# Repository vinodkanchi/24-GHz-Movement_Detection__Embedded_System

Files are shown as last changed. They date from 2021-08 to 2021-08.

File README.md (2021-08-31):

# 24-GHz-Movement_Detection__Embedded_System
The project is movement detection system where we design a PCB board for a Bandpass filter for allowing specific frequency using KiCad, then we do an embedded detection system using FreeSo-2, here we use ADC,DAC and LED's. Finally the next step is to test the model for the required frequency and gain measurements.

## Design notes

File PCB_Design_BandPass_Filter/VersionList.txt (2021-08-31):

22.05.2021, Vinod Kumar Kanchi
------------------------

Note: Every Version gets an entry, explaining their stpeciality. e.g.:

15.03.2021 - Astabel Multivibrarot, Vesion 1.0
------------------------------------------------
Feature: Single Supply Version, Four layer PCB

Radar_1v1.0

 Inital layout

Radar_1v1.1
 Changed a few resources after review by Prof. Hubrich. 
 Changed With long track from Radar sensor to capacitor,Resistor, capacitor and to Amplifier ---- Now having comparitable short track from Radar sensor to capacitor,resistor and amplifier.
 Track on 5V power plane --- Made 5V power plane on layer 2. Elimanted track from P1 to P4 pin 6 and 7.
 Rearranged few components.

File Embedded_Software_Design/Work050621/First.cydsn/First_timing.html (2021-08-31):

# Static Timing Analysis

Project : | First
Build Time : | 06/06/21 22:14:28
Device : | CY8C5888AXI-LP096
Temperature : | -40C - 85/125C
VDDA : | 5.00
VDDABUF : | 5.00
VDDD : | 5.00
VDDIO0 : | 5.00
VDDIO1 : | 5.00
VDDIO2 : | 5.00
VDDIO3 : | 5.00
VUSB : | 5.00
Voltage : | 5.0

Expand All | Collapse All | Show All Paths | Hide All Paths

+ Timing Violation Section

No Timing Violations

+ Clock Summary Section

Clock | Domain | Nominal Frequency | Required Frequency | Maximum Frequency | Violation
ADC_DelSig_Ext_CP_Clk | ADC_DelSig_Ext_CP_Clk | 24.000 MHz | 24.000 MHz | N/A
ADC_DelSig_Ext_CP_Clk(routed) | ADC_DelSig_Ext_CP_Clk(routed) | 24.000 MHz | 24.000 MHz | N/A
ClockBlock/aclk_glb_ff_0 | ClockBlock/aclk_glb_ff_0 | UNKNOWN | UNKNOWN | N/A
CyILO | CyILO | 1.000 kHz | 1.000 kHz | N/A
CyIMO | CyIMO | 3.000 MHz | 3.000 MHz | N/A
CyMASTER_CLK | CyMASTER_CLK | 24.000 MHz | 24.000 MHz | N/A
CyBUS_CLK | CyMASTER_CLK | 24.000 MHz | 24.000 MHz | 62.649 MHz
ADC_DelSig_theACLK | CyMASTER_CLK | 127.660 kHz | 127.660 kHz | N/A
UART_IntClock | CyMASTER_CLK | 76.677 kHz | 76.677 kHz | 49.694 MHz
WaveDAC8_DacClk | CyMASTER_CLK | 10.000 kHz | 10.000 kHz | N/A
CyPLL_OUT | CyPLL_OUT | 24.000 MHz | 24.000 MHz | N/A
WaveDAC8_DacClk(routed) | WaveDAC8_DacClk(routed) | 10.000 kHz | 10.000 kHz | N/A
\ADC_DelSig:DSM\/dec_clock | \ADC_DelSig:DSM\/dec_clock | UNKNOWN | UNKNOWN | N/A

+ Register to Register Section

+ Setup Subsection

+ Source Clock : CyBUS_CLK : Positive edge(Required Frequency 24 MHz)

+ Destination Clock : UART_IntClock : Positive edge(Required Frequency 76.6773 kHz)

Path Delay Requirement : 41.6667ns(24 MHz)

Affects clock : CyMASTER_CLK

Source | Destination | FMax | Delay (ns) | Slack (ns) | Violation
Rx_1(0)/fb | \UART:BUART:sRX:RxShifter:u0\/route_si | 62.649 MHz | 15.962 | 25.705

Type | Location | Fanout | Instance/Net | Source | Dest | Delay (ns)
iocell4 | P2[0] | 1 | Rx_1(0) | Rx_1(0)/in_clock | Rx_1(0)/fb | 2.187
Route | | 1 | Net_21 | Rx_1(0)/fb | \UART:BUART:rx_postpoll\/main_1 | 4.664
macrocell6 | U(0,4) | 1 | \UART:BUART:rx_postpoll\ | \UART:BUART:rx_postpoll\/main_1 | \UART:BUART:rx_postpoll\/q | 3.350
Route | | 1 | \UART:BUART:rx_postpoll\ | \UART:BUART:rx_postpoll\/q | \UART:BUART:sRX:RxShifter:u0\/route_si | 2.291
datapathcell3 | U(0,4) | 1 | \UART:BUART:sRX:RxShifter:u0\ | | SETUP | 3.470
Clock | | | | | Skew | 0.000
Rx_1(0)/fb | \UART:BUART:rx_last\/main_0 | 87.268 MHz | 11.459 | 30.208

Type | Location | Fanout | Instance/Net | Source | Dest | Delay (ns)
iocell4 | P2[0] | 1 | Rx_1(0) | Rx_1(0)/in_clock | Rx_1(0)/fb | 2.187
Route | | 1 | Net_21 | Rx_1(0)/fb | \UART:BUART:rx_last\/main_0 | 5.762
macrocell25 | U(0,3) | 1 | \UART:BUART:rx_last\ | | SETUP | 3.510
Clock | | | | | Skew | 0.000
Rx_1(0)/fb | \UART:BUART:rx_state_2\/main_8 | 87.352 MHz | 11.448 | 30.219

Type | Location | Fanout | Instance/Net | Source | Dest | Delay (ns)
iocell4 | P2[0] | 1 | Rx_1(0) | Rx_1(0)/in_clock | Rx_1(0)/fb | 2.187
Route | | 1 | Net_21 | Rx_1(0)/fb | \UART:BUART:rx_state_2\/main_8 | 5.751
macrocell19 | U(0,3) | 1 | \UART:BUART:rx_state_2\ | | SETUP | 3.510
Clock | | | | | Skew | 0.000
Rx_1(0)/fb | \UART:BUART:pollcount_1\/main_3 | 88.747 MHz | 11.268 | 30.399

Type | Location | Fanout | Instance/Net | Source | Dest | Delay (ns)
iocell4 | P2[0] | 1 | Rx_1(0) | Rx_1(0)/in_clock | Rx_1(0)/fb | 2.187
Route | | 1 | Net_21 | Rx_1(0)/fb | \UART:BUART:pollcount_1\/main_3 | 5.571
macrocell22 | U(0,5) | 1 | \UART:BUART:pollcount_1\ | | SETUP | 3.510
Clock | | | | | Skew | 0.000
Rx_1(0)/fb | \UART:BUART:pollcount_0\/main_2 | 88.747 MHz | 11.268 | 30.399

Type | Location | Fanout | Instance/Net | Source | Dest | Delay (ns)
iocell4 | P2[0] | 1 | Rx_1(0) | Rx_1(0)/in_clock | Rx_1(0)/fb | 2.187
Route | | 1 | Net_21 | Rx_1(0)/fb | \UART:BUART:pollcount_0\/main_2 | 5.571
macrocell23 | U(0,5) | 1 | \UART:BUART:pollcount_0\ | | SETUP | 3.510
Clock | | | | | Skew | 0.000
Rx_1(0)/fb | \UART:BUART:rx_state_0\/main_9 | 96.516 MHz | 10.361 | 31.306

Type | Location | Fanout | Instance/Net | Source | Dest | Delay (ns)
iocell4 | P2[0] | 1 | Rx_1(0) | Rx_1(0)/in_clock | Rx_1(0)/fb | 2.187
Route | | 1 | Net_21 | Rx_1(0)/fb | \UART:BUART:rx_state_0\/main_9 | 4.664
macrocell16 | U(0,4) | 1 | \UART:BUART:rx_state_0\ | | SETUP | 3.510
Clock | | | | | Skew | 0.000
Rx_1(0)/fb | \UART:BUART:rx_status_3\/main_6 | 96.516 MHz | 10.361 | 31.306

Type | Location | Fanout | Instance/Net | Source | Dest | Delay (ns)
iocell4 | P2[0] | 1 | Rx_1(0) | Rx_1(0)/in_clock | Rx_1(0)/fb | 2.187
Route | | 1 | Net_21 | Rx_1(0)/fb | \UART:BUART:rx_status_3\/main_6 | 4.664
macrocell24 | U(0,4) | 1 | \UART:BUART:rx_status_3\ | | SETUP | 3.510
Clock | | | | | Skew | 0.000

+ Source Clock : UART_IntClock : Positive edge(Required Frequency 76.6773 kHz)

+ Destination Clock : UART_IntClock : Positive edge(Required Frequency 76.6773 kHz)

Path Delay Requirement : 13041.7ns(76.6773 kHz)

Source | Destination | FMax | Delay (ns) | Slack (ns) | Violation
\UART:BUART:tx_state_2\/q | \UART:BUART:sTX:sCLOCK:TxBitClkGen\/cs_addr_0 | 49.694 MHz | 20.123 | 13021.544

Type | Location | Fanout | Instance/Net | Source | Dest | Delay (ns)
macrocell13 | U(1,3) | 1 | \UART:BUART:tx_state_2\ | \UART:BUART:tx_state_2\/clock_0 | \UART:BUART:tx_state_2\/q | 1.250
Route | | 1 | \UART:BUART:tx_state_2\ | \UART:BUART:tx_state_2\/q | \UART:BUART:counter_load_not\/main_3 | 5.686
macrocell2 | U(1,5) | 1 | \UART:BUART:counter_load_not\ | \UART:BUART:counter_load_not\/main_3 | \UART:BUART:counter_load_not\/q | 3.350
Route | | 1 | \UART:BUART:counter_load_not\ | \UART:BUART:counter_load_not\/q | \UART:BUART:sTX:sCLOCK:TxBitClkGen\/cs_addr_0 | 3.647
datapathcell2 | U(1,3) | 1 | \UART:BUART:sTX:sCLOCK:TxBitClkGen\ | | SETUP | 6.190
Clock | | | | | Skew | 0.000
\UART:BUART:tx_state_1\/q | \UART:BUART:sTX:sCLOCK:TxBitClkGen\/cs_addr_0 | 49.803 MHz | 20.079 | 13021.588

Type | Location | Fanout | Instance/Net | Source | Dest | Delay (ns)
macrocell11 | U(1,4) | 1 | \UART:BUART:tx_state_1\ | \UART:BUART:tx_state_1\/clock_0 | \UART:BUART:tx_state_1\/q | 1.250
Route | | 1 | \UART:BUART:tx_state_1\ | \UART:BUART:tx_state_1\/q | \UART:BUART:counter_load_not\/main_0 | 5.642
macrocell2 | U(1,5) | 1 | \UART:BUART:counter_load_not\ | \UART:BUART:counter_load_not\/main_0 | \UART:BUART:counter_load_not\/q | 3.350
Route | | 1 | \UART:BUART:counter_load_not\ | \UART:BUART:counter_load_not\/q | \UART:BUART:sTX:sCLOCK:TxBitClkGen\/cs_addr_0 | 3.647
datapathcell2 | U(1,3) | 1 | \UART:BUART:sTX:sCLOCK:TxBitClkGen\ | | SETUP | 6.190
Clock | | | | | Skew | 0.000
\UART:BUART:tx_state_0\/q | \UART:BUART:sTX:sCLOCK:TxBitClkGen\/cs_addr_0 | 50.355 MHz | 19.859 | 13021.808

Type | Location | Fanout | Instance/Net | Source | Dest | Delay (ns)
macrocell12 | U(0,4) | 1 | \UART:BUART:tx_state_0\ | \UART:BUART:tx_state_0\/clock_0 | \UART:BUART:tx_state_0\/q | 1.250
Route | | 1 | \UART:BUART:tx_state_0\ | \UART:BUART:tx_state_0\/q | \UART:BUART:counter_load_not\/main_1 | 5.422
macrocell2 | U(1,5) | 1 | \UART:BUART:counter_load_not\ | \UART:BUART:counter_load_not\/main_1 | \UART:BUART:counter_load_not\/q | 3.350
Route | | 1 | \UART:BUART:counter_load_not\ | \UART:BUART:counter_load_not\/q | \UART:BUART:sTX:sCLOCK:TxBitClkGen\/cs_addr_0 | 3.647
datapathcell2 | U(1,3) | 1 | \UART:BUART:sTX:sCLOCK:TxBitClkGen\ | | SETUP | 6.190
Clock | | | | | Skew | 0.000
\UART:BUART:sTX:sCLOCK:TxBitClkGen\/ce0_reg | \UART:BUART:sTX:sCLOCK:TxBitClkGen\/cs_addr_0 | 52.907 MHz | 18.901 | 13022.766

Type | Location | Fanout | Instance/Net | Source | Dest | Delay (ns)
datapathcell2 | U(1,3) | 1 | \UART:BUART:sTX:sCLOCK:TxBitClkGen\ | \UART:BUART:sTX:sCLOCK:TxBitClkGen\/clock | \UART:BUART:sTX:sCLOCK:TxBitClkGen\/ce0_reg | 0.190
Route | | 1 | \UART:BUART:tx_bitclk_enable_pre\ | \UART:BUART:sTX:sCLOCK:TxBitClkGen\/ce0_reg | \UART:BUART:counter_load_not\/main_2 | 5.524
macrocell2 | U(1,5) | 1 | \UART:BUART:counter_load_not\ | \UART:BUART:counter_load_not\/main_2 | \UART:BUART:counter_load_not\/q | 3.350
Route | | 1 | \UART:BUART:counter_load_not\ | \UART:BUART:counter_load_not\/q | \UART:BUART:sTX:sCLOCK:TxBitClkGen\/cs_addr_0 | 3.647
datapathcell2 | U(1,3) | 1 | \UART:BUART:sTX:sCLOCK:TxBitClkGen\ | | SETUP | 6.190
Clock | | | | | Skew | 0.000
\UART:BUART:tx_ctrl_mark_last\/q | \UART:BUART:sRX:RxBitCounter\/load | 53.359 MHz | 18.741 | 13022.926

Type | Location | Fanout | Instance/Net | Source | Dest | Delay (ns)
macrocell15 | U(1,4) | 1 | \UART:BUART:tx_ctrl_mark_last\ | \UART:BUART:tx_ctrl_mark_last\/clock_0 | \UART:BUART:tx_ctrl_mark_last\/q | 1.250
Route | | 1 | \UART:BUART:tx_ctrl_mark_last\ | \UART:BUART:tx_ctrl_mark_last\/q | \UART:BUART:rx_counter_load\/main_0 | 6.478
macrocell5 | U(1,3) | 1 | \UART:BUART:rx_counter_load\ | \UART:BUART:rx_counter_load\/main_0 | \UART:BUART:rx_counter_load\/q | 3.350
Route | | 1 | \UART:BUART:rx_counter_load\ | \UART:BUART:rx_counter_load\/q | \UART:BUART:sRX:RxBitCounter\/load | 2.303
count7cell | U(0,3) | 1 | \UART:BUART:sRX:RxBitCounter\ | | SETUP | 5.360
Clock | | | | | Skew | 0.000
\UART:BUART:rx_state_0\/q | \UART:BUART:sRX:RxBitCounter\/load | 55.402 MHz | 18.050 | 13023.617

Type | Location | Fanout | Instance/Net | Source | Dest | Delay (ns)
macrocell16 | U(0,4) | 1 | \UART:BUART:rx_state_0\ | \UART:BUART:rx_state_0\/clock_0 | \UART:BUART:rx_state_0\/q | 1.250
Route | | 1 | \UART:BUART:rx_state_0\ | \UART:BUART:rx_state_0\/q | \UART:BUART:rx_counter_load\/main_1 | 5.787
macrocell5 | U(1,3) | 1 | \UART:BUART:rx_counter_load\ | \UART:BUART:rx_counter_load\/main_1 | \UART:BUART:rx_counter_load\/q | 3.350
Route | | 1 | \UART:BUART:rx_counter_load\ | \UART:BUART:rx_counter_load\/q | \UART:BUART:sRX:RxBitCounter\/load | 2.303
count7cell | U(0,3) | 1 | \UART:BUART:sRX:RxBitCounter\ | | SETUP | 5.360
Clock | | | | | Skew | 0.000
\UART:BUART:tx_state_2\/q | \UART:BUART:sTX:TxSts\/status_0 | 58.751 MHz | 17.021 | 13024.646

Type | Location | Fanout | Instance/Net | Source | Dest | Delay (ns)
macrocell13 | U(1,3) | 1 | \UART:BUART:tx_state_2\ | \UART:BUART:tx_state_2\/clock_0 | \UART:BUART:tx_state_2\/q | 1.250
Route | | 1 | \UART:BUART:tx_state_2\ | \UART:BUART:tx_state_2\/q | \UART:BUART:tx_status_0\/main_4 | 6.401
macrocell3 | U(0,5) | 1 | \UART:BUART:tx_status_0\ | \UART:BUART:tx_status_0\/main_4 | \UART:BUART:tx_status_0\/q | 3.350
Route | | 1 | \UART:BUART:tx_status_0\ | \UART:BUART:tx_status_0\/q | \UART:BUART:sTX:TxSts\/status_0 | 5.520
statusicell1 | U(0,5) | 1 | \UART:BUART:sTX:TxSts\ | | SETUP | 0.500
Clock | | | | | Skew | 0.000
\UART:BUART:tx_state_0\/q | \UART:BUART:sTX:TxSts\/status_0 | 59.259 MHz | 16.875 | 13024.792

Type | Location | Fanout | Instance/Net | Source | Dest | Delay (ns)
macrocell12 | U(0,4) | 1 | \UART:BUART:tx_state_0\ | \UART:BUART:tx_state_0\/clock_0 | \UART:BUART:tx_state_0\/q | 1.250
Route | | 1 | \UART:BUART:tx_state_0\ | \UART:BUART:tx_state_0\/q | \UART:BUART:tx_status_0\/main_1 | 6.255
macrocell3 | U(0,5) | 1 | \UART:BUART:tx_status_0\ | \UART:BUART:tx_status_0\/main_1 | \UART:BUART:tx_status_0\/q | 3.350
Route | | 1 | \UART:BUART:tx_status_0\ | \UART:BUART:tx_status_0\/q | \UART:BUART:sTX:TxSts\/status_0 | 5.520
statusicell1 | U(0,5) | 1 | \UART:BUART:sTX:TxSts\ | | SETUP | 0.500
Clock | | | | | Skew | 0.000
\UART:BUART:sTX:TxShifter:u0\/f0_blk_stat_comb | \UART:BUART:sTX:TxSts\/status_0 | 60.226 MHz | 16.604 | 13025.063

Type | Location | Fanout | Instance/Net | Source | Dest | Delay (ns)
datapathcell1 | U(0,5) | 1 | \UART:BUART:sTX:TxShifter:u0\ | \UART:BUART:sTX:TxShifter:u0\/clock | \UART:BUART:sTX:TxShifter:u0\/f0_blk_stat_comb | 3.580
Route | | 1 | \UART:BUART:tx_fifo_empty\ | \UART:BUART:sTX:TxShifter:u0\/f0_blk_stat_comb | \UART:BUART:tx_status_0\/main_3 | 3.654
macrocell3 | U(0,5) | 1 | \UART:BUART:tx_status_0\ | \UART:BUART:tx_status_0\/main_3 | \UART:BUART:tx_status_0\/q | 3.350
Route | | 1 | \UART:BUART:tx_status_0\ | \UART:BUART:tx_status_0\/q | \UART:BUART:sTX:TxSts\/status_0 | 5.520
statusicell1 | U(0,5) | 1 | \UART:BUART:sTX:TxSts\ | | SETUP | 0.500
Clock | | | | | Skew | 0.000
\UART:BUART:tx_state_1\/q | \UART:BUART:sTX:TxSts\/status_0 | 61.482 MHz | 16.265 | 13025.402

Type | Location | Fanout | Instance/Net | Source | Dest | Delay (ns)
macrocell11 | U(1,4) | 1 | \UART:BUART:tx_state_1\ | \UART:BUART:tx_state_1\/clock_0 | \UART:BUART:tx_state_1\/q | 1.250
Route | | 1 | \UART:BUART:tx_state_1\ | \UART:BUART:tx_state_1\/q | \UART:BUART:tx_status_0\/main_0 | 5.645
macrocell3 | U(0,5) | 1 | \UART:BUART:tx_status_0\ | \UART:BUART:tx_status_0\/main_0 | \UART:BUART:tx_status_0\/q | 3.350
Route | | 1 | \UART:BUART:tx_status_0\ | \UART:BUART:tx_status_0\/q | \UART:BUART:sTX:TxSts\/status_0 | 5.520
statusicell1 | U(0,5) | 1 | \UART:BUART:sTX:TxSts\ | | SETUP | 0.500
Clock | | | | | Skew | 0.000

+ Hold Subsection

+ Source Clock : CyBUS_CLK : Positive edge

+ Destination Clock : UART_IntClock : Positive edge

Source | Destination | Slack (ns) | Violation
Rx_1(0)/fb | \UART:BUART:rx_state_0\/main_9 | 6.851

Type | Location | Fanout | Instance/Net | Source | Dest | Delay (ns)
iocell4 | P2[0] | 1 | Rx_1(0) | Rx_1(0)/in_clock | Rx_1(0)/fb | 2.187
Route | | 1 | Net_21 | Rx_1(0)/fb | \UART:BUART:rx_state_0\/main_9 | 4.664
macrocell16 | U(0,4) | 1 | \UART:BUART:rx_state_0\ | | HOLD | 0.000
Clock | | | | | Skew | 0.000
Rx_1(0)/fb | \UART:BUART:rx_status_3\/main_6 | 6.851

Type | Location | Fanout | Instance/Net | Source | Dest | Delay (ns)
iocell4 | P2[0] | 1 | Rx_1(0) | Rx_1(0)/in_clock | Rx_1(0)/fb | 2.187
Route | | 1 | Net_21 | Rx_1(0)/fb | \UART:BUART:rx_status_3\/main_6 | 4.664
macrocell24 | U(0,4) | 1 | \UART:BUART:rx_status_3\ | | HOLD | 0.000
Clock | | | | | Skew | 0.000
Rx_1(0)/fb | \UART:BUART:pollcount_1\/main_3 | 7.758

Type | Location | Fanout | Instance/Net | Source | Dest | Delay (ns)
iocell4 | P2[0] | 1 | Rx_1(0) | Rx_1(0)/in_clock | Rx_1(0)/fb | 2.187
Route | | 1 | Net_21 | Rx_1(0)/fb | \UART:BUART:pollcount_1\/main_3 | 5.571
macrocell22 | U(0,5) | 1 | \UART:BUART:pollcount_1\ | | HOLD | 0.000
Clock | | | | | Skew | 0.000
Rx_1(0)/fb | \UART:BUART:pollcount_0\/main_2 | 7.758

Type | Location | Fanout | Instance/Net | Source | Dest | Delay (ns)
iocell4 | P2[0] | 1 | Rx_1(0) | Rx_1(0)/in_clock | Rx_1(0)/fb | 2.187
Route | | 1 | Net_21 | Rx_1(0)/fb | \UART:BUART:pollcount_0\/main_2 | 5.571
macrocell23 | U(0,5) | 1 | \UART:BUART:pollcount_0\ | | HOLD | 0.000
Clock | | | | | Skew | 0.000
Rx_1(0)/fb | \UART:BUART:rx_state_2\/main_8 | 7.938

Type | Location | Fanout | Instance/Net | Source | Dest | Delay (ns)
iocell4 | P2[0] | 1 | Rx_1(0) | Rx_1(0)/in_clock | Rx_1(0)/fb | 2.187
Route | | 1 | Net_21 | Rx_1(0)/fb | \UART:BUART:rx_state_2\/main_8 | 5.751
macrocell19 | U(0,3) | 1 | \UART:BUART:rx_state_2\ | | HOLD | 0.000
Clock | | | | | Skew | 0.000
Rx_1(0)/fb | \UART:BUART:rx_last\/main_0 | 7.949

Type | Location | Fanout | Instance/Net | Source | Dest | Delay (ns)
iocell4 | P2[0] | 1 | Rx_1(0) | Rx_1(0)/in_clock | Rx_1(0)/fb | 2.187
Route | | 1 | Net_21 | Rx_1(0)/fb | \UART:BUART:rx_last\/main_0 | 5.762
macrocell25 | U(0,3) | 1 | \UART:BUART:rx_last\ | | HOLD | 0.000
Clock | | | | | Skew | 0.000
Rx_1(0)/fb | \UART:BUART:sRX:RxShifter:u0\/route_si | 12.492

Type | Location | Fanout | Instance/Net | Source | Dest | Delay (ns)
iocell4 | P2[0] | 1 | Rx_1(0) | Rx_1(0)/in_clock | Rx_1(0)/fb | 2.187
Route | | 1 | Net_21 | Rx_1(0)/fb | \UART:BUART:rx_postpoll\/main_1 | 4.664
macrocell6 | U(0,4) | 1 | \UART:BUART:rx_postpoll\ | \UART:BUART:rx_postpoll\/main_1 | \UART:BUART:rx_postpoll\/q | 3.350
Route | | 1 | \UART:BUART:rx_postpoll\ | \UART:BUART:rx_postpoll\/q | \UART:BUART:sRX:RxShifter:u0\/route_si | 2.291
datapathcell3 | U(0,4) | 1 | \UART:BUART:sRX:RxShifter:u0\ | | HOLD | 0.000
Clock | | | | | Skew | 0.000

+ Source Clock : UART_IntClock : Positive edge

+ Destination Clock : UART_IntClock : Positive edge

Source | Destination | Slack (ns) | Violation
\UART:BUART:rx_status_3\/q | \UART:BUART:sRX:RxSts\/status_3 | 1.562

Type | Location | Fanout | Instance/Net | Source | Dest | Delay (ns)
macrocell24 | U(0,4) | 1 | \UART:BUART:rx_status_3\ | \UART:BUART:rx_status_3\/clock_0 | \UART:BUART:rx_status_3\/q | 1.250
Route | | 1 | \UART:BUART:rx_status_3\ | \UART:BUART:rx_status_3\/q | \UART:BUART:sRX:RxSts\/status_3 | 2.312
statusicell2 | U(0,4) | 1 | \UART:BUART:sRX:RxSts\ | | HOLD | -2.000
Clock | | | | | Skew | 0.000
\UART:BUART:sTX:sCLOCK:TxBitClkGen\/ce1_reg | \UART:BUART:tx_state_2\/main_4 | 2.486

Type | Location | Fanout | Instance/Net | Source | Dest | Delay (ns)
datapathcell2 | U(1,3) | 1 | \UART:BUART:sTX:sCLOCK:TxBitClkGen\ | \UART:BUART:sTX:sCLOCK:TxBitClkGen\/clock | \UART:BUART:sTX:sCLOCK:TxBitClkGen\/ce1_reg | 0.190
Route | | 1 | \UART:BUART:tx_counter_dp\ | \UART:BUART:sTX:sCLOCK:TxBitClkGen\/ce1_reg | \UART:BUART:tx_state_2\/main_4 | 2.296
macrocell13 | U(1,3) | 1 | \UART:BUART:tx_state_2\ | | HOLD | 0.000
Clock | | | | | Skew | 0.000
\UART:BUART:sTX:sCLOCK:TxBitClkGen\/ce0_reg | \UART:BUART:tx_state_2\/main_2 | 2.487

Type | Location | Fanout | Instance/Net | Source | Dest | Delay (ns)
datapathcell2 | U(1,3) | 1 | \UART:BUART:sTX:sCLOCK:TxBitClkGen\ | \UART:BUART:sTX:sCLOCK:TxBitClkGen\/clock | \UART:BUART:sTX:sCLOCK:TxBitClkGen\/ce0_reg | 0.190
Route | | 1 | \UART:BUART:tx_bitclk_enable_pre\ | \UART:BUART:sTX:sCLOCK:TxBitClkGen\/ce0_reg | \UART:BUART:tx_state_2\/main_2 | 2.297
macrocell13 | U(1,3) | 1 | \UART:BUART:tx_state_2\ | | HOLD | 0.000
Clock | | | | | Skew | 0.000
\UART:BUART:sRX:RxBitCounter\/count_4 | \UART:BUART:rx_load_fifo\/main_7 | 3.236

Type | Location | Fanout | Instance/Net | Source | Dest | Delay (ns)
count7cell | U(0,3) | 1 | \UART:BUART:sRX:RxBitCounter\ | \UART:BUART:sRX:RxBitCounter\/clock | \UART:BUART:sRX:RxBitCounter\/count_4 | 0.620
Route | | 1 | \UART:BUART:rx_count_4\ | \UART:BUART:sRX:RxBitCounter\/count_4 | \UART:BUART:rx_load_fifo\/main_7 | 2.616
macrocell17 | U(0,3) | 1 | \UART:BUART:rx_load_fifo\ | | HOLD | 0.000
Clock | | | | | Skew | 0.000
\UART:BUART:sRX:RxBitCounter\/count_4 | \UART:BUART:rx_state_2\/main_7 | 3.236

Type | Location | Fanout | Instance/Net | Source | Dest | Delay (ns)
count7cell | U(0,3) | 1 | \UART:BUART:sRX:RxBitCounter\ | \UART:BUART:sRX:RxBitCounter\/clock | \UART:BUART:sRX:RxBitCounter\/count_4 | 0.620
Route | | 1 | \UART:BUART:rx_count_4\ | \UART:BUART:sRX:RxBitCounter\/count_4 | \UART:BUART:rx_state_2\/main_7 | 2.616
macrocell19 | U(0,3) | 1 | \UART:BUART:rx_state_2\ | | HOLD | 0.000
Clock | | | | | Skew | 0.000
\UART:BUART:sRX:RxBitCounter\/count_4 | \UART:BUART:rx_state_3\/main_7 | 3.245

Type | Location | Fanout | Instance/Net | Source | Dest | Delay (ns)
count7cell | U(0,3) | 1 | \UART:BUART:sRX:RxBitCounter\ | \UART:BUART:sRX:RxBitCounter\/clock | \UART:BUART:sRX:RxBitCounter\/count_4 | 0.620
Route | | 1 | \UART:BUART:rx_count_4\ | \UART:BUART:sRX:RxBitCounter\/count_4 | \UART:BUART:rx_state_3\/main_7 | 2.625
macrocell18 | U(0,3) | 1 | \UART:BUART:rx_state_3\ | | HOLD | 0.000
Clock | | | | | Skew | 0.000
\UART:BUART:sTX:sCLOCK:TxBitClkGen\/ce1_reg | \UART:BUART:tx_state_1\/main_4 | 3.384

Type | Location | Fanout | Instance/Net | Source | Dest | Delay (ns)
datapathcell2 | U(1,3) | 1 | \UART:BUART:sTX:sCLOCK:TxBitClkGen\ | \UART:BUART:sTX:sCLOCK:TxBitClkGen\/clock | \UART:BUART:sTX:sCLOCK:TxBitClkGen\/ce1_reg | 0.190
Route | | 1 | \UART:BUART:tx_counter_dp\ | \UART:BUART:sTX:sCLOCK:TxBitClkGen\/ce1_reg | \UART:BUART:tx_state_1\/main_4 | 3.194
macrocell11 | U(1,4) | 1 | \UART:BUART:tx_state_1\ | | HOLD | 0.000
Clock | | | | | Skew | 0.000
\UART:BUART:sRX:RxBitCounter\/count_5 | \UART:BUART:rx_load_fifo\/main_6 | 3.407

Type | Location | Fanout | Instance/Net | Source | Dest | Delay (ns)
count7cell | U(0,3) | 1 | \UART:BUART:sRX:RxBitCounter\ | \UART:BUART:sRX:RxBitCounter\/clock | \UART:BUART:sRX:RxBitCounter\/count_5 | 0.620
Route | | 1 | \UART:BUART:rx_count_5\ | \UART:BUART:sRX:RxBitCounter\/count_5 | \UART:BUART:rx_load_fifo\/main_6 | 2.787
macrocell17 | U(0,3) | 1 | \UART:BUART:rx_load_fifo\ | | HOLD | 0.000
Clock | | | | | Skew | 0.000
\UART:BUART:sRX:RxBitCounter\/count_5 | \UART:BUART:rx_state_2\/main_6 | 3.407

Type | Location | Fanout | Instance/Net | Source | Dest | Delay (ns)
count7cell | U(0,3) | 1 | \UART:BUART:sRX:RxBitCounter\ | \UART:BUART:sRX:RxBitCounter\/clock | \UART:BUART:sRX:RxBitCounter\/count_5 | 0.620
Route | | 1 | \UART:BUART:rx_count_5\ | \UART:BUART:sRX:RxBitCounter\/count_5 | \UART:BUART:rx_state_2\/main_6 | 2.787
macrocell19 | U(0,3) | 1 | \UART:BUART:rx_state_2\ | | HOLD | 0.000
Clock | | | | | Skew | 0.000
\UART:BUART:sRX:RxBitCounter\/count_5 | \UART:BUART:rx_state_3\/main_6 | 3.443

Type | Location | Fanout | Instance/Net | Source | Dest | Delay (ns)
count7cell | U(0,3) | 1 | \UART:BUART:sRX:RxBitCounter\ | \UART:BUART:sRX:RxBitCounter\/clock | \UART:BUART:sRX:RxBitCounter\/count_5 | 0.620
Route | | 1 | \UART:BUART:rx_count_5\ | \UART:BUART:sRX:RxBitCounter\/count_5 | \UART:BUART:rx_state_3\/main_6 | 2.823
macrocell18 | U(0,3) | 1 | \UART:BUART:rx_state_3\ | | HOLD | 0.000
Clock | | | | | Skew | 0.000

+ Clock To Output Section

+ UART_IntClock

Source | Destination | Delay (ns)
\UART:BUART:txn\/q | Tx_1(0)_PAD | 29.316

Type | Location | Fanout | Instance/Net | Source | Dest | Delay (ns)
macrocell10 | U(1,5) | 1 | \UART:BUART:txn\ | \UART:BUART:txn\/clock_0 | \UART:BUART:txn\/q | 1.250
Route | | 1 | \UART:BUART:txn\ | \UART:BUART:txn\/q | Net_25/main_0 | 2.292
macrocell1 | U(1,5) | 1 | Net_25 | Net_25/main_0 | Net_25/q | 3.350
Route | | 1 | Net_25 | Net_25/q | Tx_1(0)/pin_input | 6.533
iocell5 | P2[1] | 1 | Tx_1(0) | Tx_1(0)/pin_input | Tx_1(0)/pad_out | 15.891
Route | | 1 | Tx_1(0)_PAD | Tx_1(0)/pad_out | Tx_1(0)_PAD | 0.000
Clock | | | | | Clock path delay | 0.000

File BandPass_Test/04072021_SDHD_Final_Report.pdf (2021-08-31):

# System Driven Hardware Design

# Summer Semester 2021

# Bandpass Test Assignment Report

Submitted by:

Vinod Kumar Kanchi (769596)

Date: 04.07.2021

Guided By:

Prof. Dr. -Ing. Stephan Bannwarth

Michael Hubrich

# Contents

Sl. No. Content | Page No.
1. | Introduction | 3
2. | Schematic and experimental setup of Bandpass Filter | 3
3. | Measurement Table | 4
4. | Simulation results from MATLAB | 5
5. | Conclusion | 6
6. | Future Scope | 6

# Introduction

A bandpass filter has been designed for 24GHz movement detection. The system takes the required signal and amplifies it for further processing.

We use a FreeSoC 2 as a test bench and measure the magnitude response in dB from the lower 3dB corner frequency to the upper 3dB corner frequency. We take 10 frequencies which are spaced equally along the logarithmic scale. A sine wave test signal is generated using a waveform DAC for different frequencies. These signals are fed to the amplifier input. The output of the amplifier is sampled with a 16-bit SD-ADC and the time domain data is transferred to MATLAB.

# Schematic and Experimental Setup:

The bandpass filter is designed as shown in the figure. The stabilizing capacitor is removed and designed for an amplification factor of 300. We reduce the voltage to the ADC by giving the DAC input to a voltage divider. Input to the Bandpass filter is to be less than 8.3mV hence we select R1 and R2 as 1k ohm and 270 ohm.

DAC is configured to 40mV. The first stage of the amplifier provides a gain of 100 and second second a gain of 3, combining to give a gain 300. The amplifier acts as 4th order bandpass filter. We use the FreeSoC 2 as a testbench.

As the voltage from a radar is very less (in the range of uV), DAC is not able to get this range of values, hence reduction of gain is necessary, to get the voltage input of the ADC, hence we change the value of R7 to 6.8k ohm. Also, that we have to give buffered input so as to isolate output to input.

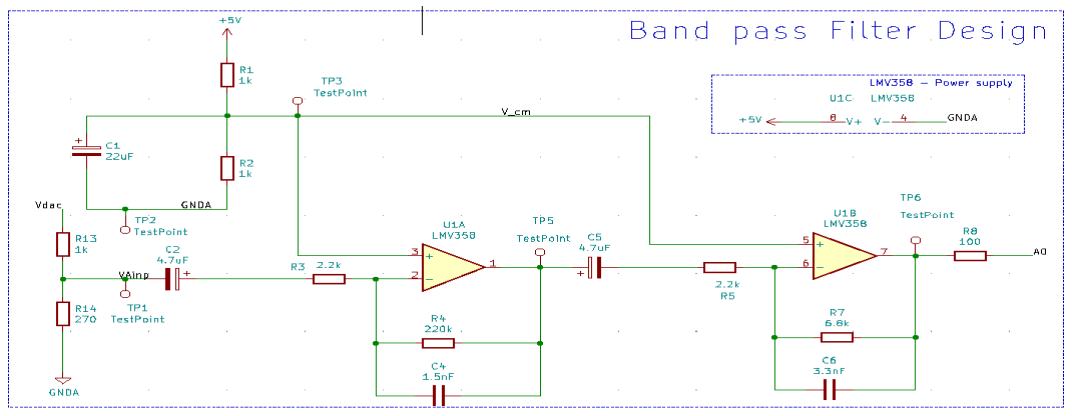
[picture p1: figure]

Figure 1: Bandpass filter schematic

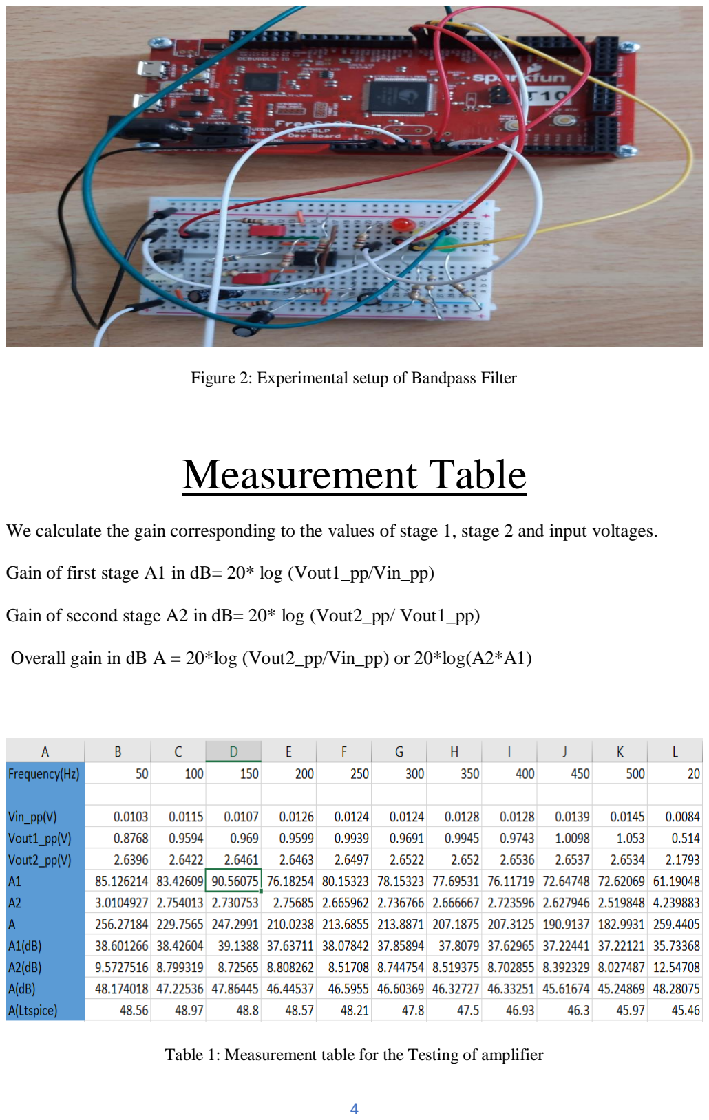
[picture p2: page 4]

Figure 2: Experimental setup of Bandpass Filter

# Measurement Table

We calculate the gain corresponding to the values of stage 1, stage 2 and input voltages.

Gain of first stage A1 in dB= 20* log (Vout1_pp/Vin_pp)

Gain of second stage A2 in dB= 20* log (Vout2_pp/ Vout1_pp)

Overall gain in dB A = 20*log (Vout2_pp/Vin_pp) or 20*log(A2*A1)

Table 1: Measurement table for the Testing of amplifier

# Simulation Results in MATLAB

A modified MATLAB program is used to simulate and measure the voltages. ADC values are sent to quantize and waveform for different samples are obtained. We get a plot that is scaled in both the signal and FFT. Another MATLAB program calling a LTspice2Matlab function is ran, which gives a plot for the LTspice and MATLAB values. LMV385.raw extracts Vout1 and Vout2 using LTspice2Matlab.m and then the data is then plotted with the measured values.

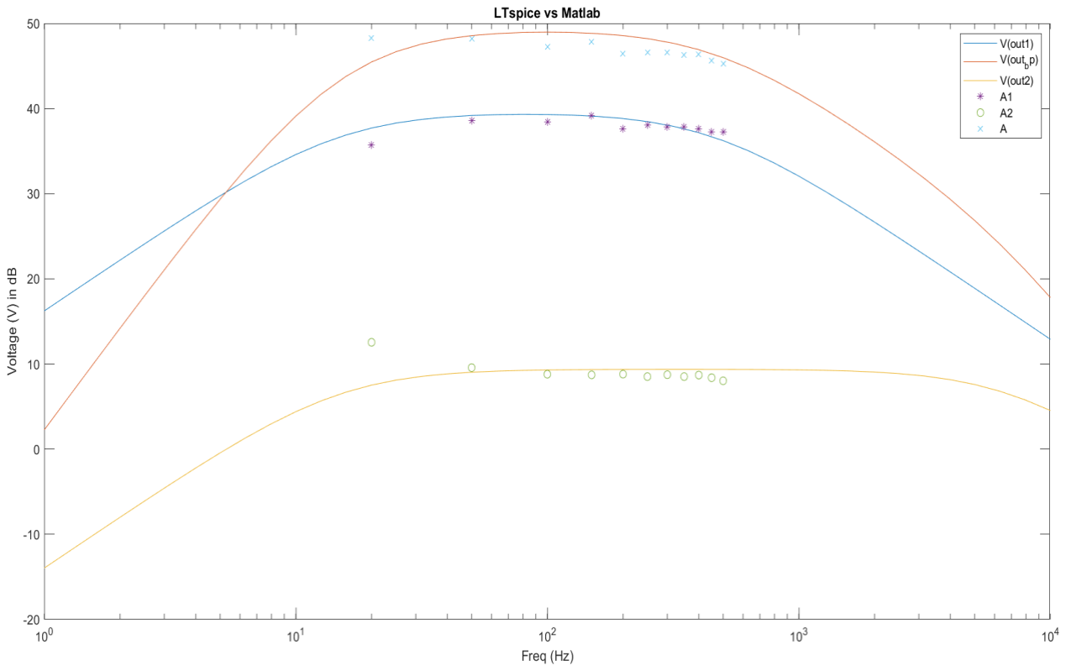
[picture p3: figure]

Figure 3: Result plotted for LTspice vs MATLAB.

# Conclusion

The readings are plotted from the simulation. The values almost match with the

values from LTspice. There have been small variations in the values as

approximations are considered in ADC and is not run in an ideal environment.

# Future Scope

We have run the experimental setup using a DAC. If the actual Radar system is used,

the amplification and pass band could be modified to get better data for processing.

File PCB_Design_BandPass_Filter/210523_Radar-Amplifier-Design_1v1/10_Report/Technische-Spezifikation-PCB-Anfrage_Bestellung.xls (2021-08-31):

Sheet: technischeSpezifikation
Anfrage
Leiterplattenspezifikation
 |  |  |  |  |  | Datum | 2021-05-22
Projektname: | Radar Amplifier PCB Design |  | LP-Bezeichn.: |  |  | v1.2
Allgemeine Anforderungen |  |  |  | Produktions-Anforderungen
IPC-A-600 G |  | Class II |  | LP-Typ: |  |  |  | Starr
RoHS kompatibel |  | Ja |  | LP-Größe: |  | +/- 0,2 mm
UL-Zertifizierung |  | Ja |  | Nutzen: |  |  |  | Nein
Hersteller Logo |  | Ja |  | Nutzengröße: |  | +/- 0,2 mm
Date Code |  | Ja |  | Stück pro Nutzen: |  | 1
E-Test |  | Ja |  | Kontur: |  |  |  | gefräst
Impedanzkontrolle |  | Ja |  | LP-Endstärke über alles: |  | 1.6mm+/- 10%
Erstmusterprüfbericht |  | Nein |  | Lagenanzahl: |  | 4
Schliffbild |  | Nein |  | Innenlagenkupfer incl. galv. Cu: |  | (µm) |  | 150
Position der UL-Nr.und Logo |  | in Daten |  | Außenlagenkupfer incl. galv. Cu: |  | (µm) |  | 150
Position Hersteller Logo |  | spezifiziert, |  | kleinste Leiterbahnbreite |  | (µm) |  | 200
und Datecode |  | Design in Cu |  | kleinster Leiterbahnabstand |  | (µm) |  | 150
 |  |  |  | Lötoberfläche: |  |  |  | chem. NI/AU
 |  |  |  | Steckergold: |  |  |  | Nein
Bohrparameter |  |  |  | Lötstoplack: |  |  |  | Grün
kleinster Bohrendurchmesser (µm) |  | 80(µm) |  | Bestückungsdruck: |  |  |  | ohne
Anzahl Bohrungen pro LP (Stück) |  | 86 |  | Farbe d. Bestückungsdruck: |  |  |  | ohne
Langlöcher |  | Nein |  | einseitiger Viadruck: |  |  |  | Nein
Randkontaktierung |  | Nein |  | Carbondruck: |  |  |  | Nein
Backdrill |  | Nein |  | Abziehlack: |  |  |  | Nein
Blind Via |  | Ja
Blind Via / Bohrebenen |  | Nein
Buried Via |  | Nein |  | Basismaterial
Buried Via / Bohrebenen |  | Nein |  | Material: |  |  |  | FR4
Microfill der Blind Via |  | Ja |  | gefülltes System: |  |  |  | Ja
Pluggen der Buried Via |  | Nein |  | TG-Wert: |  | ° Celsius |  | 150
 |  |  |  | Hersteller: |  |  |  | Isola
 |  |  |  | Materialbezeichnung: |  |  |  | R 1566W / TG 150°C
 | Einkauf
Rechnungsanschrift: |  |  |  | Einzelstückzahl:
 |  |  |  | Nutzenstückzahl:
 |  |  |  | Lieferzeit:
 |  |  |  | Versandart:
Lieferanschrift: |  |  |  | Eintrefftermin:
Kontakt Einkauf: |  |  |  |  | Kontakt Technik:
Ansprechpartner: | Vinod Kumar Kanchi |  |  | Ansprechpartner:
Email: | vinod.k.kanchi@stud.h-da/de |  |  | Email:
Telefon: |  |  |  | Telefon:
Fax: |  |  |  | Fax:
Besonderheiten:
technisches Datenblatt V2 (26.11.2008) created by Bertram / Süßlin © Elekonta Marek GmbH & Co. KG www.elekonta.de

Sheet: Lagenaufbau
Datum: | 2021-05-22 | Ansprechpartner: | 0
Projektname: | Radar Amplifier PCB Design | Email: | 0
LP-Bezeichnung: | 0 | Telefon: | 0
Revisionsstand: | 0 | Fax: | 0
technisches Datenblatt V2 (26.11.2008) created by Bertram / Süßlin © Elekonta Marek GmbH & Co. KG www.elekonta.de

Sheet: Nutzenzeichnung
Datum: | 2021-05-22 |  | Ansprechpartner: | 0
Projektname: | Radar Amplifier PCB Design |  | Email: | 0
LP-Bezeichnung: | 0 |  | Telefon: | 0
Revisionsstand: | 0 |  | Fax: | 0
 |  | Nutzenzeichnung
technisches Datenblatt V2 (26.11.2008) created by Bertram / Süßlin © Elekonta Marek GmbH & Co. KG www.elekonta.de

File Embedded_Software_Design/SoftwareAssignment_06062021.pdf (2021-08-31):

# Submission 2: Software Assignment

Vinod Kumar Kanchi

769596

State Machine Diagram:

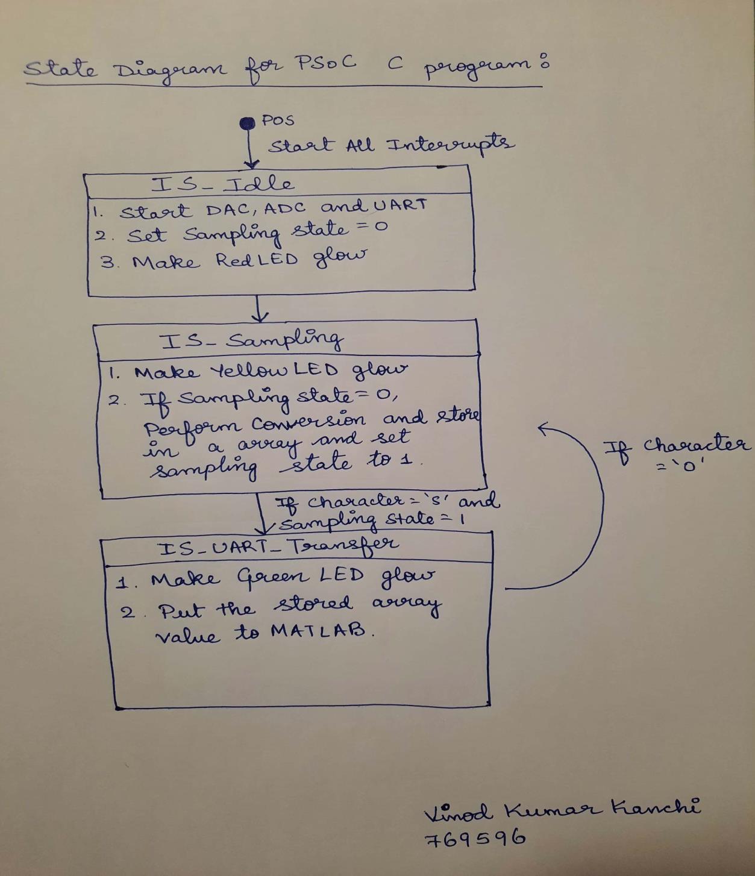
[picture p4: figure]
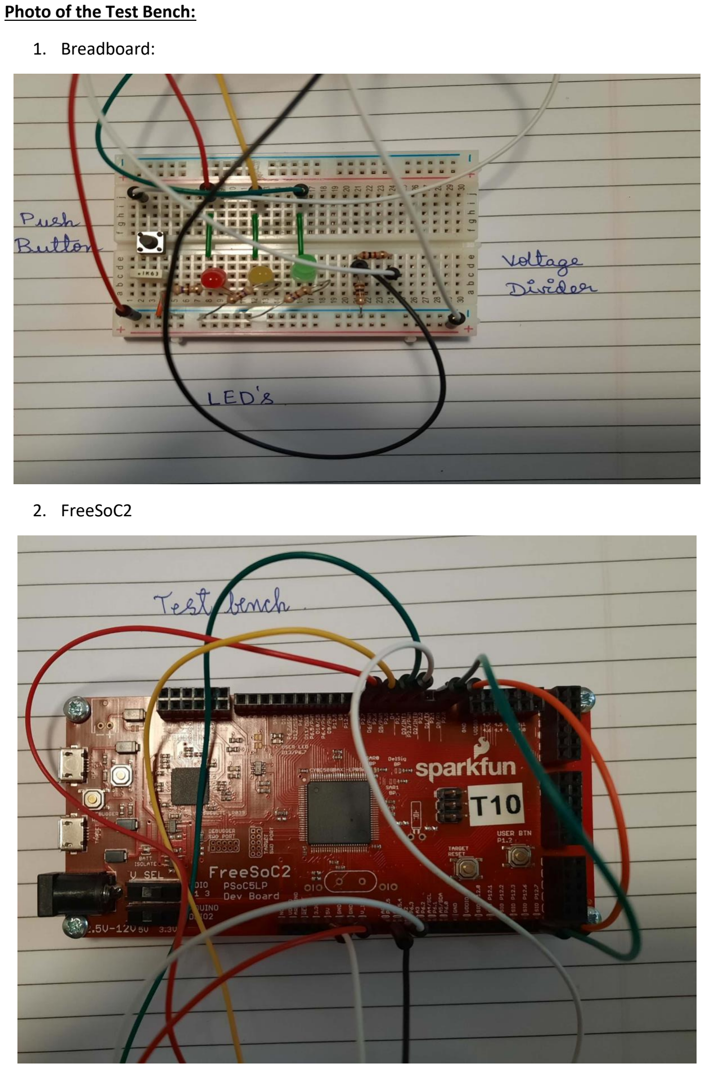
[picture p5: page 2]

Photo of the Test Bench:

1. Breadboard:
2. FreeSoC2

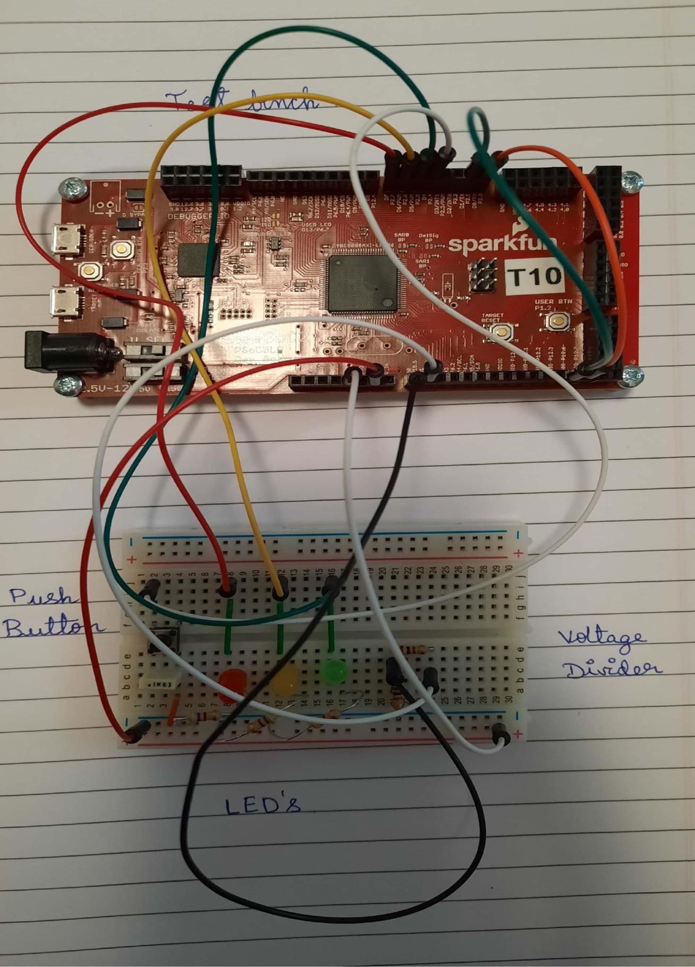
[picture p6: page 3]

3. FreeSoc2 with Breadboard

Ideas for further improvements:

1. Using a DMA for efficient memory allocation instead of array.
2. Various signals can be tested with the WaveDAC8.
3. Sending another character implying all transfers done and state could go back to idle.

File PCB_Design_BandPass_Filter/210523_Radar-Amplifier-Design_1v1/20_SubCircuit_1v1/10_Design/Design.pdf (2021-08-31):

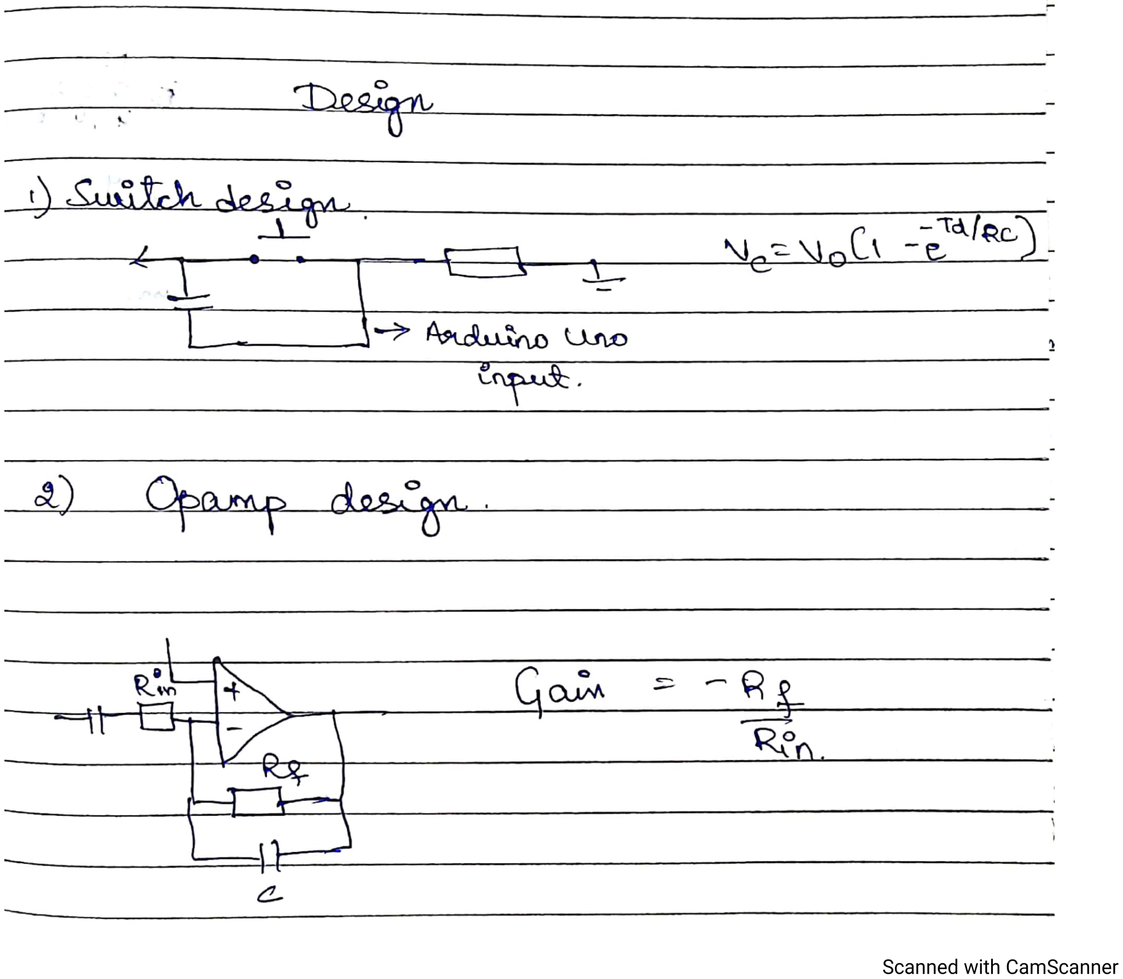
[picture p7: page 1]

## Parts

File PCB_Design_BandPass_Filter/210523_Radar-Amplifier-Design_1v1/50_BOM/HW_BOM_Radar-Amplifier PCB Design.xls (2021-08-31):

Source: | C:\Users\Vinod Kumar\Desktop\SDHD\NewRadar\NewRadar.sch
Date: | 2021-09-05 16:14
Tool: | Eeschema (5.1.9)-1
Generator: | C:\Program Files\KiCad\bin\scripting\plugins/bom_csv_grouped_by_value_with_fp.py
Component Count: | 42
 | Single Board |  |  |  | Order |  |  |  |  |  |  |  | Notes
Ref | Qnty | Value | Component Name | Footprint | Description | Vendor | single price | Total price | Order Qnty | single price | Total price | Order Number.
C1, | 1 | 22uF | CP | Capacitor_THT:C_Radial_D5.0mm_H11.0mm_P2.00mm | Polarized capacitor | Reichelt
C2, C5, | 2 | 4.7uF | CP | Capacitor_THT:C_Radial_D5.0mm_H11.0mm_P2.00mm | Polarized capacitor | Reichelt
C3,C7 | 2 | 100nF | C | Capacitor_THT:C_Rect_L7.2mm_W2.5mm_P5.00mm_FKS2_FKP2_MKS2_MKP2 | Unpolarized capacitor | Conrad
C4, | 1 | 1.5nF | C | Capacitor_THT:C_Rect_L7.2mm_W4.5mm_P5.00mm_FKS2_FKP2_MKS2_MKP2 | Unpolarized capacitor | Reichelt
C6, | 1 | 3.3nF | C | Capacitor_THT:C_Rect_L7.2mm_W4.5mm_P5.00mm_FKS2_FKP2_MKS2_MKP2 | Unpolarized capacitor | Reichelt
D1, D2, | 2 | Red LED | LED | LED_SMD:LED_1206_3216Metric_Pad1.42x1.75mm_HandSolder | Light emitting diode | Reichelt
D3, | 1 | Yellow LED | LED | LED_SMD:LED_1206_3216Metric_Pad1.42x1.75mm_HandSolder | Light emitting diode | Reichelt
D4, | 1 | Green LED | LED | LED_SMD:LED_1206_3216Metric_Pad1.42x1.75mm_HandSolder | Light emitting diode | Reichelt
J1, | 1 | Conn_01x03_Female | Conn_01x03_Female | Connector_PinSocket_2.54mm:PinSocket_1x03_P2.54mm_Horizontal | Generic connector, single row, 01x03, script generated (kicad-library-utils/schlib/autogen/connector/) | Reichelt
JP1, | 1 | SolderJumper_3_Open | SolderJumper_3_Open | Jumper:SolderJumper-3_P1.3mm_Open_RoundedPad1.0x1.5mm_NumberLabels | Solder Jumper, 3-pole, open | Reichelt
P1, | 1 | Power | Conn_01x08 | Socket_Arduino_Uno:Socket_Strip_Arduino_1x08 | Generic connector, single row, 01x08, script generated (kicad-library-utils/schlib/autogen/connector/) | Reichelt
P2, | 1 | Analog | Conn_01x06 | Socket_Arduino_Uno:Socket_Strip_Arduino_1x06 | Generic connector, single row, 01x06, script generated (kicad-library-utils/schlib/autogen/connector/) | Reichelt
P3, | 1 | Digital | Conn_01x10 | Socket_Arduino_Uno:Socket_Strip_Arduino_1x10 | Generic connector, single row, 01x10, script generated (kicad-library-utils/schlib/autogen/connector/) | Reichelt
P4, | 1 | Digital | Conn_01x08 | Socket_Arduino_Uno:Socket_Strip_Arduino_1x08 | Generic connector, single row, 01x08, script generated (kicad-library-utils/schlib/autogen/connector/) | Reichelt
P5, P6, P7, P8, | 4 | CONN_01X01 | Conn_01x01 | Socket_Arduino_Uno:Arduino_1pin | Generic connector, single row, 01x01, script generated (kicad-library-utils/schlib/autogen/connector/) | Reichelt
R1, R2, | 2 | 1k | R | Resistor_THT:R_Axial_DIN0207_L6.3mm_D2.5mm_P10.16mm_Horizontal | Resistor | Reichelt
R3, R5, | 2 | 2.2k | R | Resistor_THT:R_Axial_DIN0207_L6.3mm_D2.5mm_P10.16mm_Horizontal | Resistor | Reichelt
R4, | 1 | 220k | R | Resistor_THT:R_Axial_DIN0207_L6.3mm_D2.5mm_P10.16mm_Horizontal | Resistor | Reichelt
R6, R12, | 2 | 1k | R | Resistor_SMD:R_1206_3216Metric_Pad1.30x1.75mm_HandSolder | Resistor | Reichelt
R7, | 1 | 100k | R | Resistor_THT:R_Axial_DIN0207_L6.3mm_D2.5mm_P10.16mm_Horizontal | Resistor | Reichelt
R8, | 1 | 100 | R | Resistor_THT:R_Axial_DIN0207_L6.3mm_D2.5mm_P10.16mm_Horizontal | Resistor | Reichelt
R9, R10, R11, | 3 | 470 | R | Resistor_SMD:R_1206_3216Metric_Pad1.30x1.75mm_HandSolder | Resistor | Reichelt
SW1, | 1 | SW_Push | SW_Push | Button_Switch_THT:SW_PUSH_6mm_H7.3mm | Push button switch, generic, two pins | Reichelt
TP1, TP2, TP3, TP4, TP5, TP6, TP7, | 7 | TestPoint | TestPoint | Connector_Pin:Pin_D1.0mm_L10.0mm | test point | Reichelt
U1, | 1 | LMV358 | LMV358 | Package_DIP:DIP-8_W7.62mm_Socket | Dual Low-Voltage Rail-to-Rail Output Operational Amplifiers, SOIC-8/SSOP-8 | Reichelt

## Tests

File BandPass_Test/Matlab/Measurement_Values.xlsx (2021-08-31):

Frequency(Hz) | 50 | 100 | 150 | 200 | 250 | 300 | 350 | 400 | 450 | 500 | 20
Vin_pp(V) | 0.0103 | 0.0115 | 0.0107 | 0.0126 | 0.0124 | 0.0124 | 0.0128 | 0.0128 | 0.0139 | 0.0145 | 0.0084
Vout1_pp(V) | 0.8768 | 0.9594 | 0.969 | 0.9599 | 0.9939 | 0.9691 | 0.9945 | 0.9743 | 1.0098 | 1.053 | 0.514
Vout2_pp(V) | 2.6396 | 2.6422 | 2.6461 | 2.6463 | 2.6497 | 2.6522 | 2.652 | 2.6536 | 2.6537 | 2.6534 | 2.1793
A1 | 85.12621359 | 83.42608696 | 90.56074766 | 76.18253968 | 80.15322581 | 78.15322581 | 77.6953125 | 76.1171875 | 72.64748201 | 72.62068966 | 61.19047619
A2 | 3.010492701 | 2.754012925 | 2.730753354 | 2.756849672 | 2.66596237 | 2.736766072 | 2.666666667 | 2.723596428 | 2.627946128 | 2.519848053 | 4.239883268
A | 256.2718447 | 229.7565217 | 247.2990654 | 210.0238095 | 213.6854839 | 213.8870968 | 207.1875 | 207.3125 | 190.9136691 | 182.9931034 | 259.4404762
A1(dB) | 38.60126633 | 38.42603748 | 39.13879999 | 37.63710893 | 38.07842011 | 37.85893817 | 37.80789636 | 37.62965466 | 37.22441132 | 37.22120738 | 35.73367666
A2(dB) | 9.572751571 | 8.799319482 | 8.725649515 | 8.808261702 | 8.517080303 | 8.744753543 | 8.519374645 | 8.702855119 | 8.392329162 | 8.027487072 | 12.547078
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

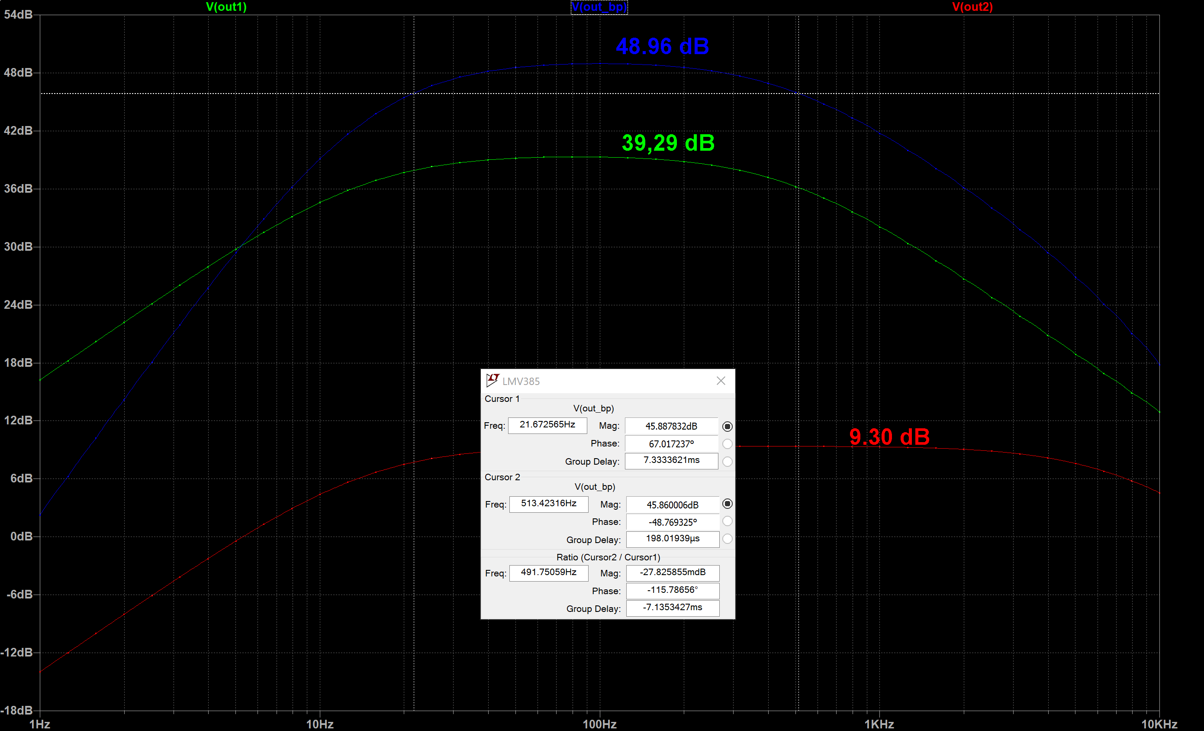
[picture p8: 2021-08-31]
BandPass_Test/Matlab/200629_LT_SpiceSim_R6_6k8_dB.png

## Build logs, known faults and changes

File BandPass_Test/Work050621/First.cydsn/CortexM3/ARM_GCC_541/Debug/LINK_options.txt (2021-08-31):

-Wl,--start-group -o "C:\\Users\\Vinod\ Kumar\\Desktop\\04.07\\Work050621\\First.cydsn\\CortexM3\\ARM_GCC_541\\Debug\\First.elf" ".\\CortexM3\\ARM_GCC_541\\Debug\\main.o" ".\\CortexM3\\ARM_GCC_541\\Debug\\cyfitter_cfg.o" ".\\CortexM3\\ARM_GCC_541\\Debug\\cymetadata.o" ".\\CortexM3\\ARM_GCC_541\\Debug\\Cm3Start.o" ".\\CortexM3\\ARM_GCC_541\\Debug\\First.a" "C:\\Program\ Files\ (x86)\\Cypress\\PSoC\ Creator\\4.4\\PSoC\ Creator\\psoc\\content\\cycomponentlibrary\\CyComponentLibrary.cylib\\CortexM3\\ARM_GCC_541\\Debug\\CyComponentLibrary.a" -mcpu=cortex-m3 -mthumb -L "Generated_Source\\PSoC5" "-Wl,-Map,.\\CortexM3\\ARM_GCC_541\\Debug/First.map" -T "Generated_Source\\PSoC5\\cm3gcc.ld" -specs=nano.specs -Wl,--gc-sections -g -ffunction-sections -Og -ffat-lto-objects -Wl,--end-group

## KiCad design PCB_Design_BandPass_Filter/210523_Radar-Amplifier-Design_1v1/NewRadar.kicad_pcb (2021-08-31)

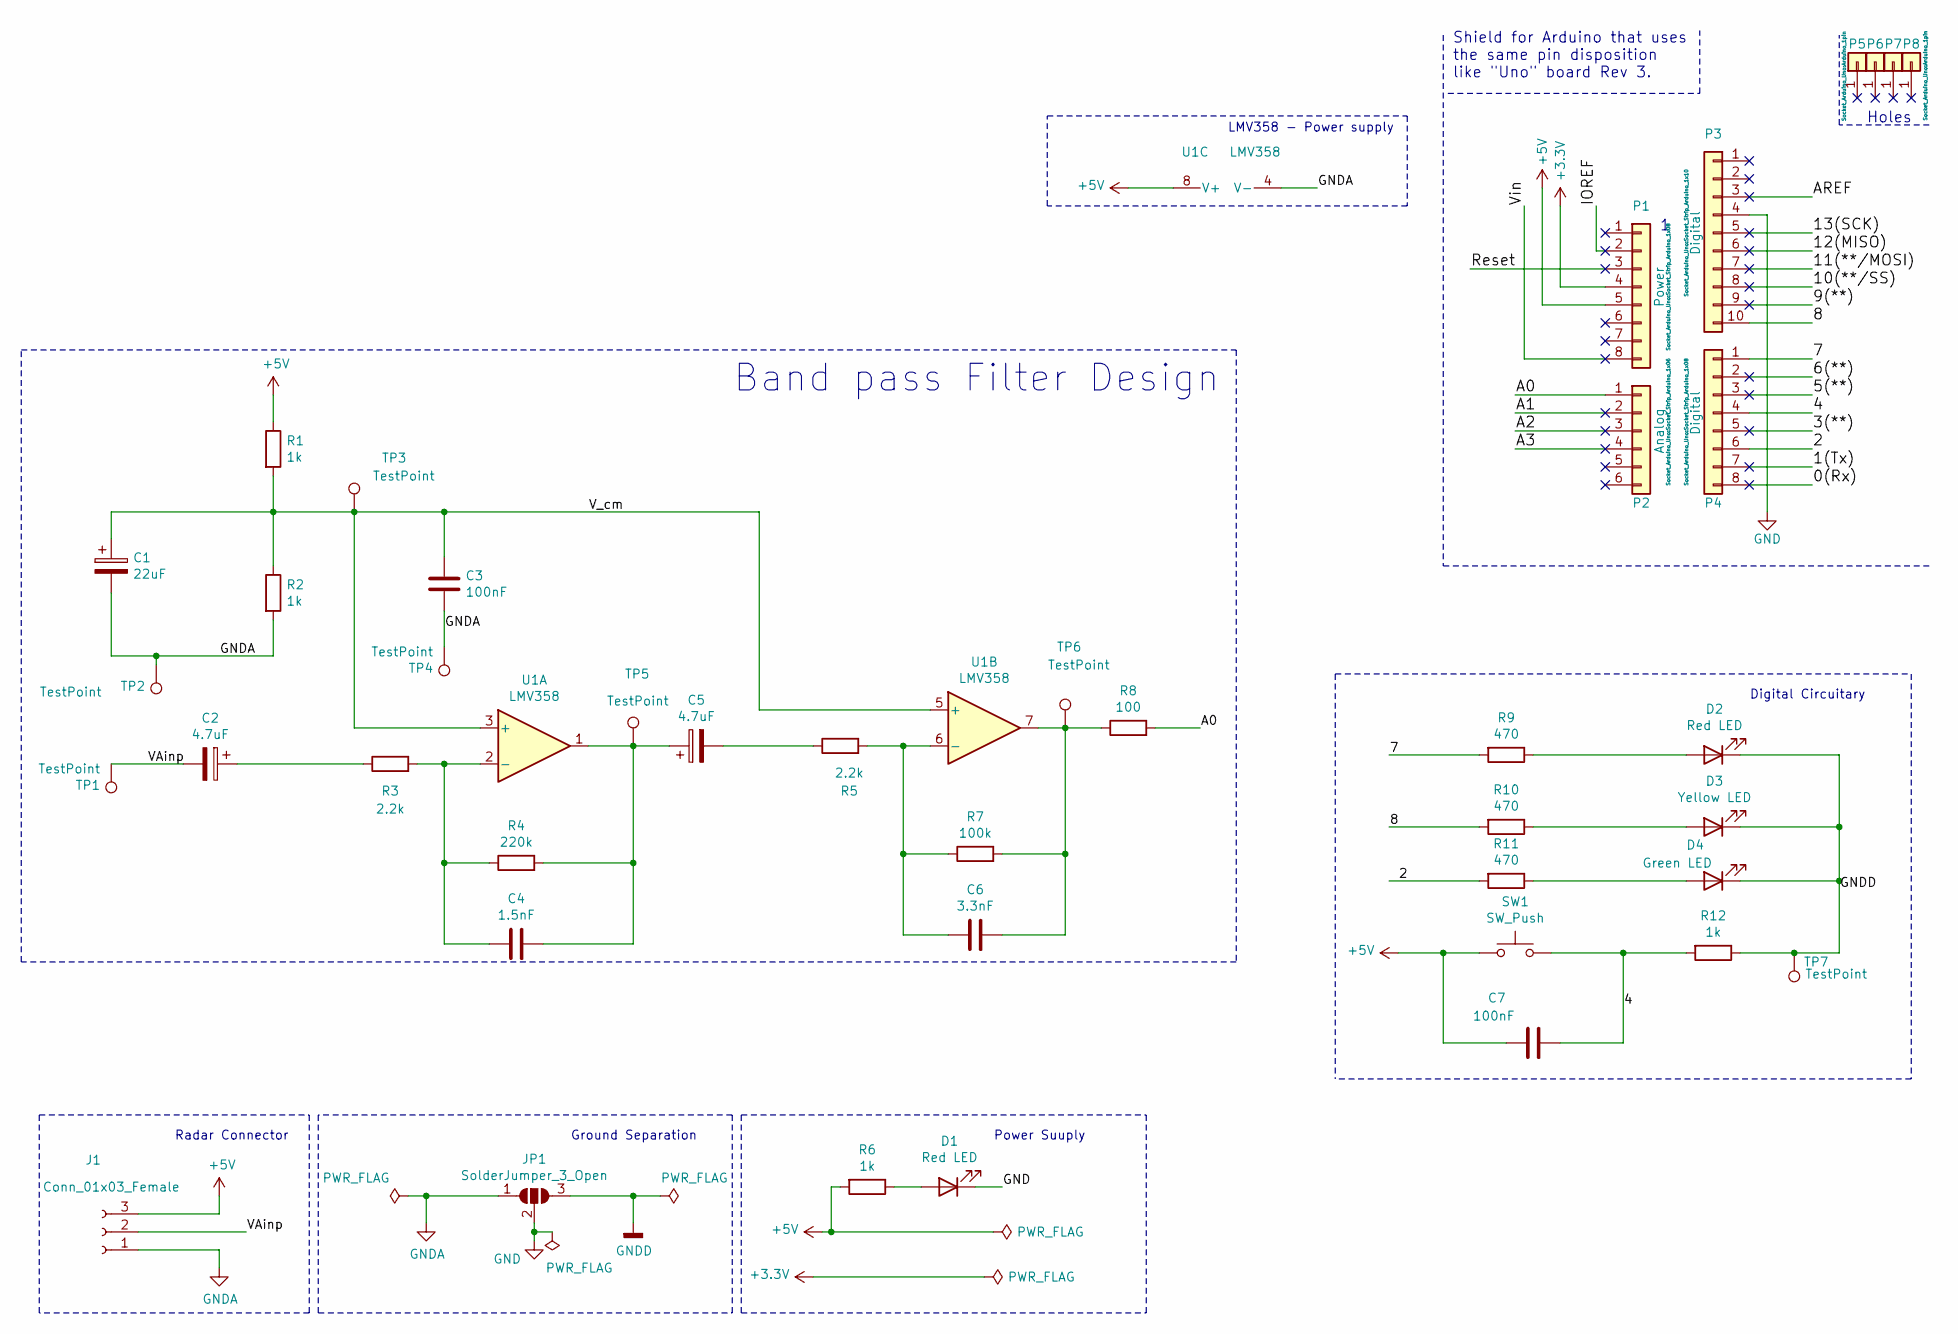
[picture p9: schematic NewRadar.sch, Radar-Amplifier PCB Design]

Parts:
C1: 22uF; C_Radial_D5.0mm_H11.0mm_P2.00mm
C2, C5: 4.7uF; C_Radial_D5.0mm_H11.0mm_P2.00mm
C3, C7: 100nF; C_Rect_L7.2mm_W2.5mm_P5.00mm_FKS2_FKP2_MKS2_MKP2
C4: 1.5nF; C_Rect_L7.2mm_W4.5mm_P5.00mm_FKS2_FKP2_MKS2_MKP2
C6: 3.3nF; C_Rect_L7.2mm_W4.5mm_P5.00mm_FKS2_FKP2_MKS2_MKP2
D1, D2: Red LED; LED_1206_3216Metric_Pad1.42x1.75mm_HandSolder
D3: Yellow LED; LED_1206_3216Metric_Pad1.42x1.75mm_HandSolder
D4: Green LED; LED_1206_3216Metric_Pad1.42x1.75mm_HandSolder
J1: Conn_01x03_Female; PinSocket_1x03_P2.54mm_Horizontal
JP1: SolderJumper_3_Open; SolderJumper-3_P1.3mm_Open_RoundedPad1.0x1.5mm_NumberLabels
P1: Power; Socket_Strip_Arduino_1x08
P2: Analog; Socket_Strip_Arduino_1x06
P3: Digital; Socket_Strip_Arduino_1x10
P4: Digital; Socket_Strip_Arduino_1x08
P5, P6, P7, P8: CONN_01X01; Arduino_1pin
R1, R2: 1k; R_Axial_DIN0207_L6.3mm_D2.5mm_P10.16mm_Horizontal
R3, R5: 2.2k; R_Axial_DIN0207_L6.3mm_D2.5mm_P10.16mm_Horizontal
R4: 220k; R_Axial_DIN0207_L6.3mm_D2.5mm_P10.16mm_Horizontal
R6, R12: 1k; R_1206_3216Metric_Pad1.30x1.75mm_HandSolder
R7: 100k; R_Axial_DIN0207_L6.3mm_D2.5mm_P10.16mm_Horizontal
R8: 100; R_Axial_DIN0207_L6.3mm_D2.5mm_P10.16mm_Horizontal
R9, R10, R11: 470; R_1206_3216Metric_Pad1.30x1.75mm_HandSolder
SW1: SW_Push; SW_PUSH_6mm_H7.3mm
TP1, TP2, TP3, TP4, TP5, TP6, TP7: TestPoint; Pin_D1.0mm_L10.0mm
U1: LMV358; DIP-8_W7.62mm_Socket

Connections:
+3V3: P1.4
+5V: C7.1, J1.3, P1.5, R1.1, R6.2, SW1.1, U1.8 (V+)
/0(Rx): P4.8
/1(Tx): P4.7
/2: P4.6, R11.2
/3(**): P4.5
/4: C7.2, P4.4, R12.2, SW1.2
/5(**): P4.3
/6(**): P4.2
/7: P4.1, R9.2
/8: P3.10, R10.2
/9(**): P3.9
/10(**/SS): P3.8
/11(**/MOSI): P3.7
/12(MISO): P3.6
/13(SCK): P3.5
/A0: P2.1, R8.2
/A1: P2.2
/A2: P2.3
/A3: P2.4
/AREF: P3.3
/IOREF: P1.2
/Reset: P1.3
/VAinp: C2.2, J1.2, TP1.1
/V_cm: C1.1, C3.1, R1.2, R2.1, TP3.1, U1.3 (+), U1.5 (+)
/Vin: P1.8
GND: D1.1 (K), JP1.2 (C), P3.4
GNDA: C1.2, C3.2, J1.1, JP1.1 (A), R2.2, TP2.1, TP4.1, U1.4 (V-)
GNDD: D2.1 (K), D3.1 (K), D4.1 (K), JP1.3 (B), R12.1, TP7.1
unnamed: C2.1, R3.1
unnamed: C4.1, C5.1, R4.2, TP5.1, U1.1
unnamed: C4.2, R3.2, R4.1, U1.2 (-)
unnamed: C5.2, R5.1
unnamed: C6.1, R7.2, R8.1, TP6.1, U1.7
unnamed: C6.2, R5.2, R7.1, U1.6 (-)
unnamed: D1.2 (A), R6.1
unnamed: D2.2 (A), R9.1
unnamed: D3.2 (A), R10.1
unnamed: D4.2 (A), R11.1

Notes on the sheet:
Holes
Shield for Arduino that uses the same pin disposition like "Uno" board Rev 3.
Band pass Filter Design
LMV358 - Power supply
Digital Circuitary
Radar Connector
Ground Separation
Power Suuply

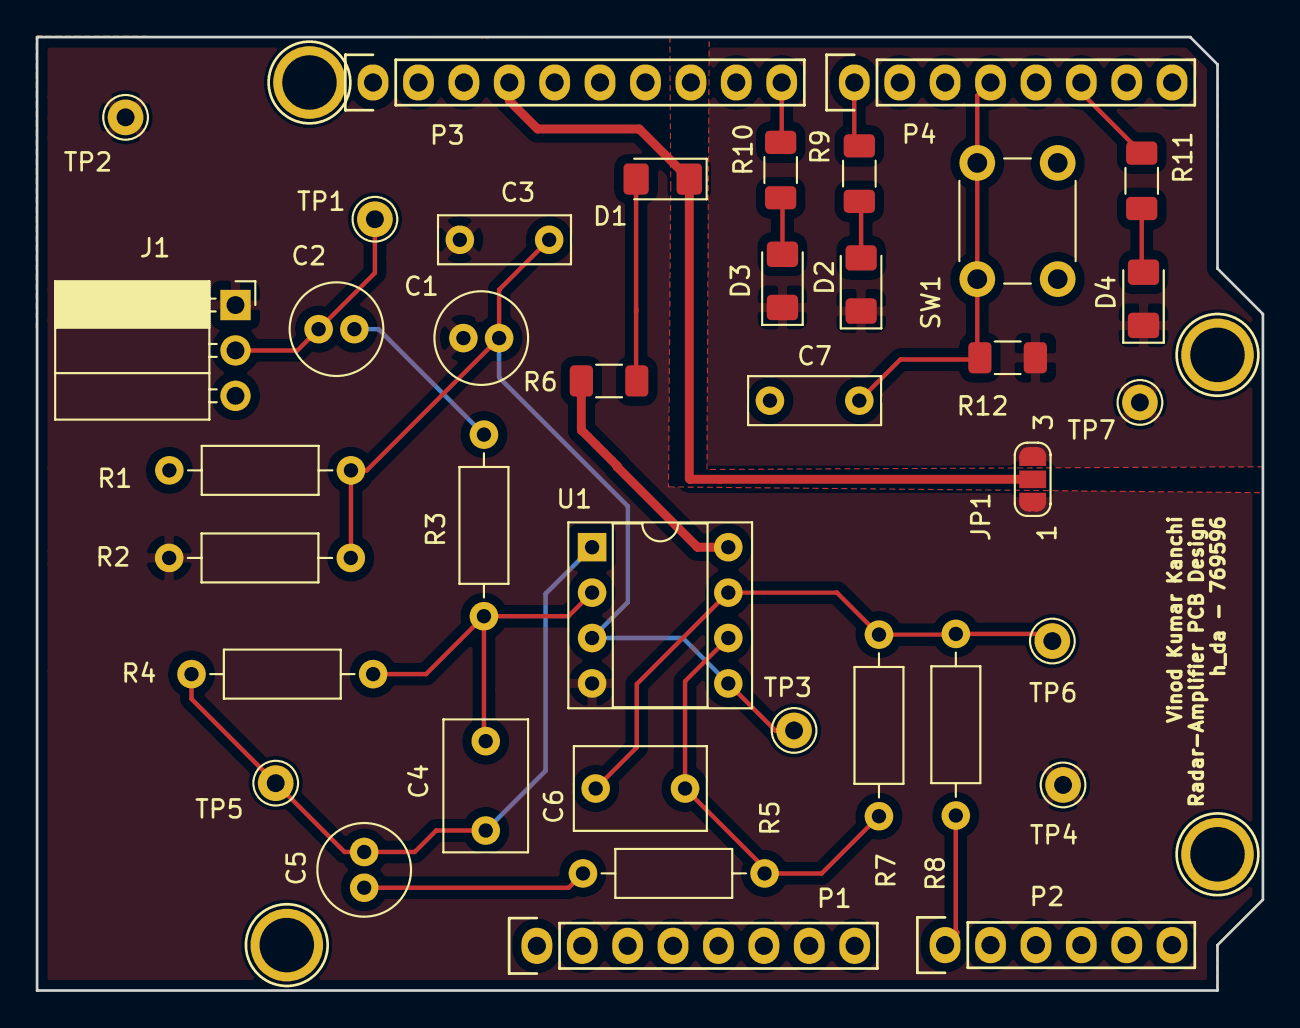
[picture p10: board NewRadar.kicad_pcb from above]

Board: 4 copper layers, 68.6 x 53.3 mm, 42 parts (0 on the bottom side), 21 nets.

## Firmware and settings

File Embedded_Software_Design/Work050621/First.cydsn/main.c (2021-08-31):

/* ===============================================================
 *
 * Copyright YOUR COMPANY, THE YEAR
 * All Rights Reserved
 * UNPUBLISHED, LICENSED SOFTWARE.
 *
 * CONFIDENTIAL AND PROPRIETARY INFORMATION
 * WHICH IS THE PROPERTY OF your company.
 *
 * ===============================================================
 * ===============================================================
 * Name                 : Vinod Kumar Kanchi
 * Matriculation Number : 769596
 * Major                : Communication
 * Email Id             : vinod.k.kanchi@stud.h-da.de
 * ===============================================================*/

#include "project.h"

uint16_t SampledArray[1024];                    //To store the sampled data into an array.

uint8_t character;                              //A global variable to check the character received or sent to and from MATLAB.
uint8_t SamplingState;                          //A global variable to check if sampling is done correctly.

typedef enum
{   IS_Idle,
    IS_Sampling,
    IS_UART_Transfer,
}System_state;                                  //To define the different states.

System_state state = IS_Idle;                   //Initialize the state to idle.

void ISR_button(void)
{
    state= IS_Sampling;
    Pin_PushButton_ClearInterrupt();            
}                                               //An interrupt to detect the button press and to clear the interrupt OF THE Pin.

void UART_INT(void)
{
    character= UART_GetChar();
    isr_UART_ClearPending();
}                                               //An interrupt to detect the character and to clear the interrupt in the UART.

CY_ISR_PROTO(isr_ADC);

CY_ISR(isr_ADC)
{
    isr_ADC_ClearPending();
    
}                                               //An interrupt to clear the interrupt of ADC.
    
int main(void)
{
    
    CyGlobalIntEnable;                          /* Enable global interrupts. */
   
    isr_ADC_StartEx(isr_ADC);
    isr_PushButton_StartEx(ISR_button);
    isr_UART_StartEx(UART_INT);                 //Starts all the interrupts.
    
    
    
    for(;;)
    {
        switch(state)
            {
                case IS_Idle:
                       
                    WaveDAC8_Start();
                    ADC_DelSig_Start(); 
                    UART_Start();                               //Starts all the devices.
                
                    SamplingState = 0;      //Set the sampling state to 0 initially.
                    PinYellow_Write(0);
                    PinRed_Write(1);
                    PinGreen_Write(0);
                                            //Make Red LED glow and other LED's Off to indicate idle state.
                    break;
                            
                case IS_Sampling:
                                                                 
                    PinYellow_Write(1);
                    PinRed_Write(0);
                    PinGreen_Write(0);      //Make Yellow LED glow and other LED's Off to indicate Sampling state.
                    if(SamplingState ==0)   //If sampling state is 0 and push button is pressed starts converting.
                    {
                        ADC_DelSig_StartConvert();  //ADC Starts conversion.
                        for(uint16_t i=0; i<1024; i++)
                        {
                            ADC_DelSig_IsEndConversion(ADC_DelSig_WAIT_FOR_RESULT);
                            SampledArray[i] = ADC_DelSig_GetResult16();
                            
                        }                   /*A loop of 1024 to stop the conversion and sampling at each point
                                                and store the value in an array.*/
                        SamplingState = 1;  //To indicate sampling is done for once.
                    }

                    if(character=='s' && SamplingState==1)
                    {
                        state = IS_UART_Transfer;
                        SamplingState = 0;
                        character = 0;
                     }                      /*If character is 's' and sampling state is 1, then change the state to transfer,
                                                 and reset sampling state and character to 0 for once*/
                        break;
                        
                case IS_UART_Transfer:
                            
                      for(uint16_t i=0;i<1024;i++)
                         {
                            UART_PutChar(SampledArray[i]);
                            UART_PutChar(SampledArray[i]>>8);
                         }                  /*Loop to transfer data to MATLAB, 8 bits at a time and then right shift 
                                              8 times to get the next 8 bits.*/  
            
                        PinGreen_Write(1);
                        PinRed_Write(0);
                        PinYellow_Write(0); //Make Green LED glow and other LED's Off to indicate Transfer state.
                                            
                        if(character == 'o')
                        {
                             state=IS_Sampling; //If MATLAB sends character 'o' then move back to sampling state.
                        }
                    break;
        }   
    }

}

/*End of File*/

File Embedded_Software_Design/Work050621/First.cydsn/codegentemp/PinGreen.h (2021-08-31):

/*******************************************************************************
* File Name: PinGreen.h  
* Version 2.20
*
* Description:
*  This file contains Pin function prototypes and register defines
*
* Note:
*
********************************************************************************
* Copyright 2008-2015, Cypress Semiconductor Corporation.  All rights reserved.
* You may use this file only in accordance with the license, terms, conditions, 
* disclaimers, and limitations in the end user license agreement accompanying 
* the software package with which this file was provided.
*******************************************************************************/

#if !defined(CY_PINS_PinGreen_H) /* Pins PinGreen_H */
#define CY_PINS_PinGreen_H

#include "cytypes.h"
#include "cyfitter.h"
#include "cypins.h"
#include "PinGreen_aliases.h"

/* APIs are not generated for P15[7:6] */
#if !(CY_PSOC5A &&\
	 PinGreen__PORT == 15 && ((PinGreen__MASK & 0xC0) != 0))


/***************************************
*        Function Prototypes             
***************************************/    

/**
* \addtogroup group_general
* @{
*/
void    PinGreen_Write(uint8 value);
void    PinGreen_SetDriveMode(uint8 mode);
uint8   PinGreen_ReadDataReg(void);
uint8   PinGreen_Read(void);
void    PinGreen_SetInterruptMode(uint16 position, uint16 mode);
uint8   PinGreen_ClearInterrupt(void);
/** @} general */

/***************************************
*           API Constants        
***************************************/
/**
* \addtogroup group_constants
* @{
*/
    /** \addtogroup driveMode Drive mode constants
     * \brief Constants to be passed as "mode" parameter in the PinGreen_SetDriveMode() function.
     *  @{
     */
        #define PinGreen_DM_ALG_HIZ         PIN_DM_ALG_HIZ
        #define PinGreen_DM_DIG_HIZ         PIN_DM_DIG_HIZ
        #define PinGreen_DM_RES_UP          PIN_DM_RES_UP
        #define PinGreen_DM_RES_DWN         PIN_DM_RES_DWN
        #define PinGreen_DM_OD_LO           PIN_DM_OD_LO
        #define PinGreen_DM_OD_HI           PIN_DM_OD_HI
        #define PinGreen_DM_STRONG          PIN_DM_STRONG
        #define PinGreen_DM_RES_UPDWN       PIN_DM_RES_UPDWN
    /** @} driveMode */
/** @} group_constants */
    
/* Digital Port Constants */
#define PinGreen_MASK               PinGreen__MASK
#define PinGreen_SHIFT              PinGreen__SHIFT
#define PinGreen_WIDTH              1u

/* Interrupt constants */
#if defined(PinGreen__INTSTAT)
/**
* \addtogroup group_constants
* @{
*/
    /** \addtogroup intrMode Interrupt constants
     * \brief Constants to be passed as "mode" parameter in PinGreen_SetInterruptMode() function.
     *  @{
     */
        #define PinGreen_INTR_NONE      (uint16)(0x0000u)
        #define PinGreen_INTR_RISING    (uint16)(0x0001u)
        #define PinGreen_INTR_FALLING   (uint16)(0x0002u)
        #define PinGreen_INTR_BOTH      (uint16)(0x0003u) 
    /** @} intrMode */
/** @} group_constants */

    #define PinGreen_INTR_MASK      (0x01u) 
#endif /* (PinGreen__INTSTAT) */


/***************************************
*             Registers        
***************************************/

/* Main Port Registers */
/* Pin State */
#define PinGreen_PS                     (* (reg8 *) PinGreen__PS)
/* Data Register */
#define PinGreen_DR                     (* (reg8 *) PinGreen__DR)
/* Port Number */
#define PinGreen_PRT_NUM                (* (reg8 *) PinGreen__PRT) 
/* Connect to Analog Globals */                                                  
#define PinGreen_AG                     (* (reg8 *) PinGreen__AG)                       
/* Analog MUX bux enable */
#define PinGreen_AMUX                   (* (reg8 *) PinGreen__AMUX) 
/* Bidirectional Enable */                                                        
#define PinGreen_BIE                    (* (reg8 *) PinGreen__BIE)
/* Bit-mask for Aliased Register Access */
#define PinGreen_BIT_MASK               (* (reg8 *) PinGreen__BIT_MASK)
/* Bypass Enable */
#define PinGreen_BYP                    (* (reg8 *) PinGreen__BYP)
/* Port wide control signals */                                                   
#define PinGreen_CTL                    (* (reg8 *) PinGreen__CTL)
/* Drive Modes */
#define PinGreen_DM0                    (* (reg8 *) PinGreen__DM0) 
#define PinGreen_DM1                    (* (reg8 *) PinGreen__DM1)
#define PinGreen_DM2                    (* (reg8 *) PinGreen__DM2) 
/* Input Buffer Disable Override */
#define PinGreen_INP_DIS                (* (reg8 *) PinGreen__INP_DIS)
/* LCD Common or Segment Drive */
#define PinGreen_LCD_COM_SEG            (* (reg8 *) PinGreen__LCD_COM_SEG)
/* Enable Segment LCD */
#define PinGreen_LCD_EN                 (* (reg8 *) PinGreen__LCD_EN)
/* Slew Rate Control */
#define PinGreen_SLW                    (* (reg8 *) PinGreen__SLW)
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

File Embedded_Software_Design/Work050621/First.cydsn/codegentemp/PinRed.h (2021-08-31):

/*******************************************************************************
* File Name: PinRed.h  
* Version 2.20
*
* Description:
*  This file contains Pin function prototypes and register defines
*
* Note:
*
********************************************************************************
* Copyright 2008-2015, Cypress Semiconductor Corporation.  All rights reserved.
* You may use this file only in accordance with the license, terms, conditions, 
* disclaimers, and limitations in the end user license agreement accompanying 
* the software package with which this file was provided.
*******************************************************************************/

#if !defined(CY_PINS_PinRed_H) /* Pins PinRed_H */
#define CY_PINS_PinRed_H

#include "cytypes.h"
#include "cyfitter.h"
#include "cypins.h"
#include "PinRed_aliases.h"

/* APIs are not generated for P15[7:6] */
#if !(CY_PSOC5A &&\
	 PinRed__PORT == 15 && ((PinRed__MASK & 0xC0) != 0))


/***************************************
*        Function Prototypes             
***************************************/    

/**
* \addtogroup group_general
* @{
*/
void    PinRed_Write(uint8 value);
void    PinRed_SetDriveMode(uint8 mode);
uint8   PinRed_ReadDataReg(void);
uint8   PinRed_Read(void);
void    PinRed_SetInterruptMode(uint16 position, uint16 mode);
uint8   PinRed_ClearInterrupt(void);
/** @} general */

/***************************************
*           API Constants        
***************************************/
/**
* \addtogroup group_constants
* @{
*/
    /** \addtogroup driveMode Drive mode constants
     * \brief Constants to be passed as "mode" parameter in the PinRed_SetDriveMode() function.
     *  @{
     */
        #define PinRed_DM_ALG_HIZ         PIN_DM_ALG_HIZ
        #define PinRed_DM_DIG_HIZ         PIN_DM_DIG_HIZ
        #define PinRed_DM_RES_UP          PIN_DM_RES_UP
        #define PinRed_DM_RES_DWN         PIN_DM_RES_DWN
        #define PinRed_DM_OD_LO           PIN_DM_OD_LO
        #define PinRed_DM_OD_HI           PIN_DM_OD_HI
        #define PinRed_DM_STRONG          PIN_DM_STRONG
        #define PinRed_DM_RES_UPDWN       PIN_DM_RES_UPDWN
    /** @} driveMode */
/** @} group_constants */
    
/* Digital Port Constants */
#define PinRed_MASK               PinRed__MASK
#define PinRed_SHIFT              PinRed__SHIFT
#define PinRed_WIDTH              1u

/* Interrupt constants */
#if defined(PinRed__INTSTAT)
/**
* \addtogroup group_constants
* @{
*/
    /** \addtogroup intrMode Interrupt constants
     * \brief Constants to be passed as "mode" parameter in PinRed_SetInterruptMode() function.
     *  @{
     */
        #define PinRed_INTR_NONE      (uint16)(0x0000u)
        #define PinRed_INTR_RISING    (uint16)(0x0001u)
        #define PinRed_INTR_FALLING   (uint16)(0x0002u)
        #define PinRed_INTR_BOTH      (uint16)(0x0003u) 
    /** @} intrMode */
/** @} group_constants */

    #define PinRed_INTR_MASK      (0x01u) 
#endif /* (PinRed__INTSTAT) */


/***************************************
*             Registers        
***************************************/

/* Main Port Registers */
/* Pin State */
#define PinRed_PS                     (* (reg8 *) PinRed__PS)
/* Data Register */
#define PinRed_DR                     (* (reg8 *) PinRed__DR)
/* Port Number */
#define PinRed_PRT_NUM                (* (reg8 *) PinRed__PRT) 
/* Connect to Analog Globals */                                                  
#define PinRed_AG                     (* (reg8 *) PinRed__AG)                       
/* Analog MUX bux enable */
#define PinRed_AMUX                   (* (reg8 *) PinRed__AMUX) 
/* Bidirectional Enable */                                                        
#define PinRed_BIE                    (* (reg8 *) PinRed__BIE)
/* Bit-mask for Aliased Register Access */
#define PinRed_BIT_MASK               (* (reg8 *) PinRed__BIT_MASK)
/* Bypass Enable */
#define PinRed_BYP                    (* (reg8 *) PinRed__BYP)
/* Port wide control signals */                                                   
#define PinRed_CTL                    (* (reg8 *) PinRed__CTL)
/* Drive Modes */
#define PinRed_DM0                    (* (reg8 *) PinRed__DM0) 
#define PinRed_DM1                    (* (reg8 *) PinRed__DM1)
#define PinRed_DM2                    (* (reg8 *) PinRed__DM2) 
/* Input Buffer Disable Override */
#define PinRed_INP_DIS                (* (reg8 *) PinRed__INP_DIS)
/* LCD Common or Segment Drive */
#define PinRed_LCD_COM_SEG            (* (reg8 *) PinRed__LCD_COM_SEG)
/* Enable Segment LCD */
#define PinRed_LCD_EN                 (* (reg8 *) PinRed__LCD_EN)
/* Slew Rate Control */
#define PinRed_SLW                    (* (reg8 *) PinRed__SLW)
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
